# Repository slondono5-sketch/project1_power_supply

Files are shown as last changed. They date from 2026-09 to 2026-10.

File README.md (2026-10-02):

<div align="center">

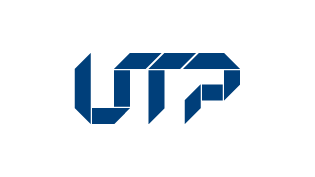
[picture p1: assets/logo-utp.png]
Universidad Tecnológica de Pereira


# ⚡ Fuente de Alimentación Multisalida

**Prototipado Electrónico** · Ingeniería Mecatrónica · 2026-2

*Santiago Londoño Valencia*





</div>

---

## 📌 Descripción

Fuente de laboratorio que convierte la tensión AC de un transformador en cinco salidas DC reguladas, mediante rectificación con puente de diodos, filtrado capacitivo y convertidores DC/DC integrados en la PCB.

## 🔌 Salidas

| Salida | Corriente máx. |
|:---:|:---:|
| **+12 V** | 5 A |
| **+5 V** | 5 A |
| **+3.3 V** | 3 A |
| **−12 V** | 1 A |
| **1.25 – 15 V** | 3 A |

## 📁 Estructura

```
📦 Proyecto
 ┣ 📂 PCB
 ┃ ┗ 📂 Trunk            → Proyecto de Altium Designer
 ┣ 📂 Documentacion      → Especificaciones, requerimientos, diagramas y datasheets
 ┃ ┗ 📂 Diagramas        → Diagrama de diseño de alto nivel en DRAW.IO
 ┣ 📂 Librerias          → Símbolos y footprints propios
 ┗ 📂 assets             → Imágenes del README
```

👉 Empieza por la [documentación del proyecto](Documentacion/README.md).

---

<div align="center">
<sub>Universidad Tecnológica de Pereira · 2026</sub>
</div>

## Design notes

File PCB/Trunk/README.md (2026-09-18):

# project1_power_supply
This project contains the main files for the altium project for the LAB power supply

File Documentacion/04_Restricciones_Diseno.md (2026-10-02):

# 04 – Restricciones de Diseño

## Restricciones eléctricas

| ID | Restricción | Impacto en el diseño |
|---|---|---|
| RD-01 | La entrada es un transformador AC del laboratorio. | Su tensión y potencia limitan el bus DC y la potencia simultánea disponible. Si es menor a 300 VA, no todas las salidas podrán operar a plena carga al mismo tiempo. |
| RD-02 | La rectificación debe hacerse con puente de diodos y filtrado capacitivo. | Se descarta la corrección de factor de potencia y la rectificación síncrona. |
| RD-03 | La tensión del bus DC debe quedar entre ≈ 21 V y ≈ 30 V. | El mínimo garantiza la salida de 15 V; el máximo debe quedar por debajo de la tensión máxima de entrada de los reguladores (40 V). |
| RD-04 | Red eléctrica de 120 VAC, 60 Hz. | El rizado del bus es de 120 Hz, lo que define el tamaño del banco capacitivo. |
| RD-05 | La salida de −12 V debe generarse desde el mismo bus positivo. | Exige una topología inversora; el regulador soporta Vin + |Vout| ≈ 42 V entre sus terminales. |
| RD-06 | Toda la conversión DC/DC debe integrarse en la PCB. | No se permiten módulos DC/DC comerciales externos. |

## Restricciones térmicas

| ID | Restricción | Impacto en el diseño |
|---|---|---|
| RD-07 | Temperatura ambiente de operación de 0 a 40 °C (laboratorio). | Cálculo de disipadores con este ambiente máximo. |
| RD-08 | El puente rectificador y los reguladores disipan varios vatios. | Se requieren disipadores y encapsulados de montaje en disipador (TO-220 / TO-263, puente tipo GBJ o KBPC). |

## Restricciones de fabricación (DFM)

| ID | Restricción | Impacto en el diseño |
|---|---|---|
| RD-09 | Herramienta de diseño: Altium Designer. | Esquemáticos, PCB y librerías propias en Altium. |
| RD-10 | PCB de 2 capas, cobre de 2 oz (70 µm). | Pistas de potencia anchas o polígonos de cobre; el ancho se calcula según IPC-2221 para ≥ 10 A en el bus. |
| RD-11 | Se priorizan componentes THT y SMD de tamaño manejable (≥ 0805). | Facilita el ensamble y la reparación manual. |
| RD-12 | Separación entre la zona de 120 VAC y la de baja tensión. | Distancias de aislamiento (creepage/clearance) en la PCB o primario fuera de la PCB. |

## Restricciones mecánicas

| ID | Restricción | Impacto en el diseño |
|---|---|---|
| RD-13 | Las salidas deben conectarse con bornes de laboratorio. | Bornes tipo binding post / banana de 4 mm rateados para ≥ 10 A. |
| RD-14 | El transformador, los disipadores y el banco de capacitores son voluminosos. | Definen el tamaño mínimo de la PCB y del encapsulado. |
| RD-15 | Se requiere ventilación. | Encapsulado con perforaciones o ventilador. |

## Restricciones del proyecto

| ID | Restricción | Impacto en el diseño |
|---|---|---|
| RD-16 | Presupuesto académico limitado. | Se priorizan reguladores integrados de bajo costo frente a controladores con MOSFET externos. |
| RD-17 | Tiempo de desarrollo de un semestre (2026-2). | Se usan topologías con diseños de referencia del fabricante. |
| RD-18 | Disponibilidad de componentes en Colombia. | Se selecciona una alternativa para cada componente crítico. |

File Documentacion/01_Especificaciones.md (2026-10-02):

# 01 – Especificaciones del Proyecto

## 1. Descripción general

Fuente de alimentación multisalida, alimentada desde un transformador AC del laboratorio, destinada a energizar prototipos y proyectos electrónicos de laboratorio. La energía AC se rectifica con un puente de diodos, se filtra capacitivamente para formar un bus DC no regulado (VIN DC) y desde este bus cinco convertidores DC/DC independientes, integrados en la misma PCB, generan las salidas reguladas.

## 2. Especificaciones de entrada

| Parámetro | Valor |
|---|---|
| Red eléctrica | 120 VAC ±10 %, 60 Hz (Colombia) |
| Transformador | Primario 120 VAC / secundario 18 VAC, potencia ≥ 300 VA |
| Rectificación | Puente de diodos de onda completa |
| Frecuencia de rizado | 120 Hz |
| Filtrado | Banco capacitivo ≈ 30 000 µF |
| Bus DC (VIN DC) nominal | ≈ 24 V |
| Bus DC mínimo (valle de rizado, carga plena, red −10 %) | ≈ 21 V |
| Bus DC máximo (sin carga, red +10 %) | ≈ 30 V |

## 3. Especificaciones de salida

| Salida | Tensión | Corriente máx. | Corriente de diseño (+25 %) | Potencia máx. | Topología |
|---|---|---|---|---|---|
| OUT1 | +12 V | 5 A | 6.25 A | 60 W | Buck |
| OUT2 | +5 V | 5 A | 6.25 A | 25 W | Buck |
| OUT3 | +3.3 V | 3 A | 3.75 A | 9.9 W | Buck |
| OUT4 | −12 V | 1 A | 1.25 A | 12 W | Buck-boost inversor |
| OUT5 | 1.25 – 15 V ajustable | 3 A | 3.75 A | 45 W | Buck ajustable |
| **Total** | | | | **≈ 152 W** | |

Parámetros de calidad objetivo en todas las salidas:

| Parámetro | Objetivo |
|---|---|
| Tolerancia de tensión (salidas fijas) | ±3 % |
| Rizado de salida | ≤ 100 mVpp (≤ 50 mVpp en +3.3 V) |
| Regulación de carga (10 % → 100 %) | ≤ 2 % |
| Eficiencia por convertidor | ≥ 80 % a carga plena |

## 4. Presupuesto de potencia (power budget)

| Salida | P salida | η estimada | P entrada |
|---|---|---|---|
| +12 V | 60 W | 90 % | 66.7 W |
| +5 V | 25 W | 88 % | 28.4 W |
| +3.3 V | 9.9 W | 85 % | 11.6 W |
| −12 V | 12 W | 80 % | 15.0 W |
| Variable | 45 W | 85 % | 52.9 W |
| **Total sobre el bus DC** | **152 W** | | **≈ 175 W** |

- Corriente promedio del bus DC a tensión mínima: 175 W / 21 V ≈ **8.3 A**
- Potencia aparente del transformador (factor ≈ 1.7 por filtro capacitivo): 175 W × 1.7 ≈ **300 VA**
- Corriente de primario: 300 VA / 120 V ≈ **2.5 A**

## 5. Cálculos de la etapa de entrada

**Tensión del bus:**

- Pico del secundario: 18 V × √2 ≈ 25.5 V
- Caída del puente (2 diodos a ~8 A): ≈ 2 V → pico DC ≈ 23.5 V
- Sin carga, la regulación del transformador (~8 %) y la red al +10 % llevan el bus a ≈ 30 V

**Capacitor de filtro:**

C = I / (f · ΔV) = 8.3 A / (120 Hz × 3 V) ≈ 23 000 µF → se especifican 3 × 10 000 µF (30 000 µF), con lo que ΔV ≈ 2.3 Vpp.

**Margen para la salida variable:** con 21 V de bus mínimo y 15 V de salida, el ciclo de trabajo máximo es ≈ 0.71, dentro del rango del convertidor.

## 6. Protecciones especificadas

| Protección | Ubicación |
|---|---|
| Fusible de acción lenta | Primario del transformador |
| Varistor (MOV) | Entrada AC |
| Interruptor de encendido | Primario |
| TVS | Bus DC |
| Fusible / PTC por salida | Cada salida |
| Limitación de corriente y apagado térmico | Integrados en cada regulador |
| Diodo de protección contra tensión inversa | Cada salida |
| Resistencia de descarga | Banco de capacitores |
| LED indicador | Bus DC y cada salida |

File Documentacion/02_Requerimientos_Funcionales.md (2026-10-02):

# 02 – Requerimientos Funcionales

Los requerimientos funcionales describen **qué debe hacer** la fuente de alimentación.

| ID | Requerimiento | Criterio de verificación |
|---|---|---|
| RF-01 | La fuente debe recibir energía desde el transformador AC del laboratorio. | Operación correcta con el transformador especificado. |
| RF-02 | La fuente debe rectificar la tensión AC mediante un puente de diodos de onda completa. | Forma de onda rectificada observada en osciloscopio. |
| RF-03 | La fuente debe filtrar la tensión rectificada mediante un banco capacitivo y generar un bus DC (VIN DC). | Rizado del bus ≤ 3 Vpp a carga plena. |
| RF-04 | La fuente debe entregar +12 V con una corriente de hasta 5 A. | Medición con carga electrónica a 5 A, tolerancia ±3 %. |
| RF-05 | La fuente debe entregar +5 V con una corriente de hasta 5 A. | Medición con carga electrónica a 5 A, tolerancia ±3 %. |
| RF-06 | La fuente debe entregar +3.3 V con una corriente de hasta 3 A. | Medición con carga electrónica a 3 A, tolerancia ±3 %. |
| RF-07 | La fuente debe entregar −12 V con una corriente de hasta 1 A. | Medición con carga electrónica a 1 A, tolerancia ±3 %. |
| RF-08 | La fuente debe entregar una salida ajustable entre 1.25 V y 15 V con una corriente de hasta 3 A. | Barrido del potenciómetro de mínimo a máximo con carga de 3 A. |
| RF-09 | El usuario debe poder ajustar la salida variable mediante un potenciómetro accesible. | Ajuste manual sin herramientas. |
| RF-10 | La conversión DC/DC de todas las salidas debe estar integrada en la PCB de la fuente. | Inspección de la PCB. |
| RF-11 | La fuente debe poder encenderse y apagarse mediante un interruptor general. | Prueba de encendido y apagado. |
| RF-12 | La fuente debe proteger la entrada contra sobrecorriente mediante un fusible. | Inspección y coordinación del fusible. |
| RF-13 | Cada salida debe limitar su corriente ante sobrecarga o cortocircuito sin dañarse. | Prueba de cortocircuito de cada salida. |
| RF-14 | Los reguladores deben apagarse ante sobretemperatura y recuperarse al enfriarse. | Verificación con datasheet y prueba térmica. |
| RF-15 | La fuente debe indicar visualmente la presencia de tensión en el bus DC y en cada salida. | LEDs encendidos en operación normal. |
| RF-16 | Las salidas deben poder usarse simultáneamente y de forma independiente. | Prueba con varias cargas conectadas a la vez. |
| RF-17 | Todas las salidas deben compartir una referencia común (GND). | Verificación de continuidad. |
| RF-18 | El banco de capacitores debe descargarse de forma segura al apagar la fuente. | Tensión del bus < 5 V antes de 60 s después del apagado. |

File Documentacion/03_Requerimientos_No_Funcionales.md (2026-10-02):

# 03 – Requerimientos No Funcionales

Los requerimientos no funcionales describen **cómo** debe comportarse el sistema: calidad, seguridad, confiabilidad y facilidad de uso.

## Desempeño

| ID | Requerimiento |
|---|---|
| RNF-01 | El rizado de cada salida debe ser ≤ 100 mVpp (≤ 50 mVpp en +3.3 V). |
| RNF-02 | La regulación de carga debe ser ≤ 2 % entre 10 % y 100 % de carga. |
| RNF-03 | La eficiencia de cada convertidor DC/DC debe ser ≥ 80 % a carga plena. |
| RNF-04 | La respuesta transitoria ante escalones de carga no debe superar ±5 % de la tensión nominal. |

## Confiabilidad y seguridad

| ID | Requerimiento |
|---|---|
| RNF-05 | Los componentes de potencia deben dimensionarse con un margen de seguridad de 20–30 % sobre la corriente máxima. |
| RNF-06 | Los capacitores deben tener una tensión nominal de al menos 1.5 veces la tensión máxima del bus. |
| RNF-07 | La temperatura de unión de los semiconductores debe permanecer al menos 20 °C por debajo de su máximo a carga plena. |
| RNF-08 | La fuente debe operar en régimen continuo a carga plena durante al menos 1 hora sin degradación. |
| RNF-09 | La sección de 120 VAC debe quedar aislada y protegida contra contacto accidental. |
| RNF-10 | La fuente debe incluir conexión a tierra de protección para el chasis o encapsulado metálico. |

## Usabilidad

| ID | Requerimiento |
|---|---|
| RNF-11 | Las salidas deben estar claramente identificadas por tensión y polaridad. |
| RNF-12 | Los conectores de salida deben permitir conectar cables de laboratorio (bornes banana de 4 mm). |
| RNF-13 | El ajuste de la salida variable debe ser fino (potenciómetro multivuelta). |

## Mantenibilidad y fabricación

| ID | Requerimiento |
|---|---|
| RNF-14 | Los fusibles deben poder reemplazarse sin desoldar componentes. |
| RNF-15 | La PCB debe incluir puntos de prueba en el bus DC y en cada salida. |
| RNF-16 | Cada convertidor debe ocupar una zona propia de la PCB para facilitar diagnóstico y reparación. |
| RNF-17 | Los componentes deben conseguirse en distribuidores nacionales (I+D Electrónica, Sigma Electrónica, Vistronica, Ferretrónica) o internacionales (Digi-Key, Mouser, LCSC). |
| RNF-18 | El proyecto debe documentarse y versionarse en el repositorio Git con la estructura definida. |

## Costo

| ID | Requerimiento |
|---|---|
| RNF-19 | Se deben preferir componentes de bajo costo y amplia disponibilidad sin comprometer los requerimientos eléctricos. |

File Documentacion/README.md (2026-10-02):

# Documentación – Fuente de Alimentación Multisalida para Laboratorio

Proyecto 1 – Prototipado Electrónico (Ingeniería Mecatrónica, UTP 2026-2)

## Contenido de la carpeta

| Archivo | Descripción |
|---|---|
| [01_Especificaciones.md](01_Especificaciones.md) | Especificaciones técnicas del sistema y presupuesto de potencia |
| [02_Requerimientos_Funcionales.md](02_Requerimientos_Funcionales.md) | Qué debe hacer la fuente |
| [03_Requerimientos_No_Funcionales.md](03_Requerimientos_No_Funcionales.md) | Cómo debe hacerlo (calidad, seguridad, mantenibilidad) |
| [04_Restricciones_Diseno.md](04_Restricciones_Diseno.md) | Limitaciones técnicas, económicas y de fabricación |
| [05_Lista_Preliminar_Componentes.md](05_Lista_Preliminar_Componentes.md) | Componentes principales seleccionados y su justificación |
| [Diagramas/](Diagramas/README.md) | Diagrama de Bloques de Alto Nivel (HBLD) en PNG y archivo editable .drawio |

## Flujo de diseño

Requisitos del sistema → Especificaciones → Arquitectura por bloques → Selección de componentes → Captura de esquemáticos

## Control de versiones

| Versión | Fecha | Descripción |
|---|---|---|
| 0.1 | 2026-10 | Documentación inicial |
| 0.2 | 2026-10 | Se agrega el Diagrama de Bloques de Alto Nivel (HBLD) |

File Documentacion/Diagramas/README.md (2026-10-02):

<div align="center">

# 🧩 Diagrama de Bloques de Alto Nivel (HBLD)

**Fuente de Alimentación Multisalida** · Prototipado Electrónico · UTP 2026-2

</div>

---

<div align="center">

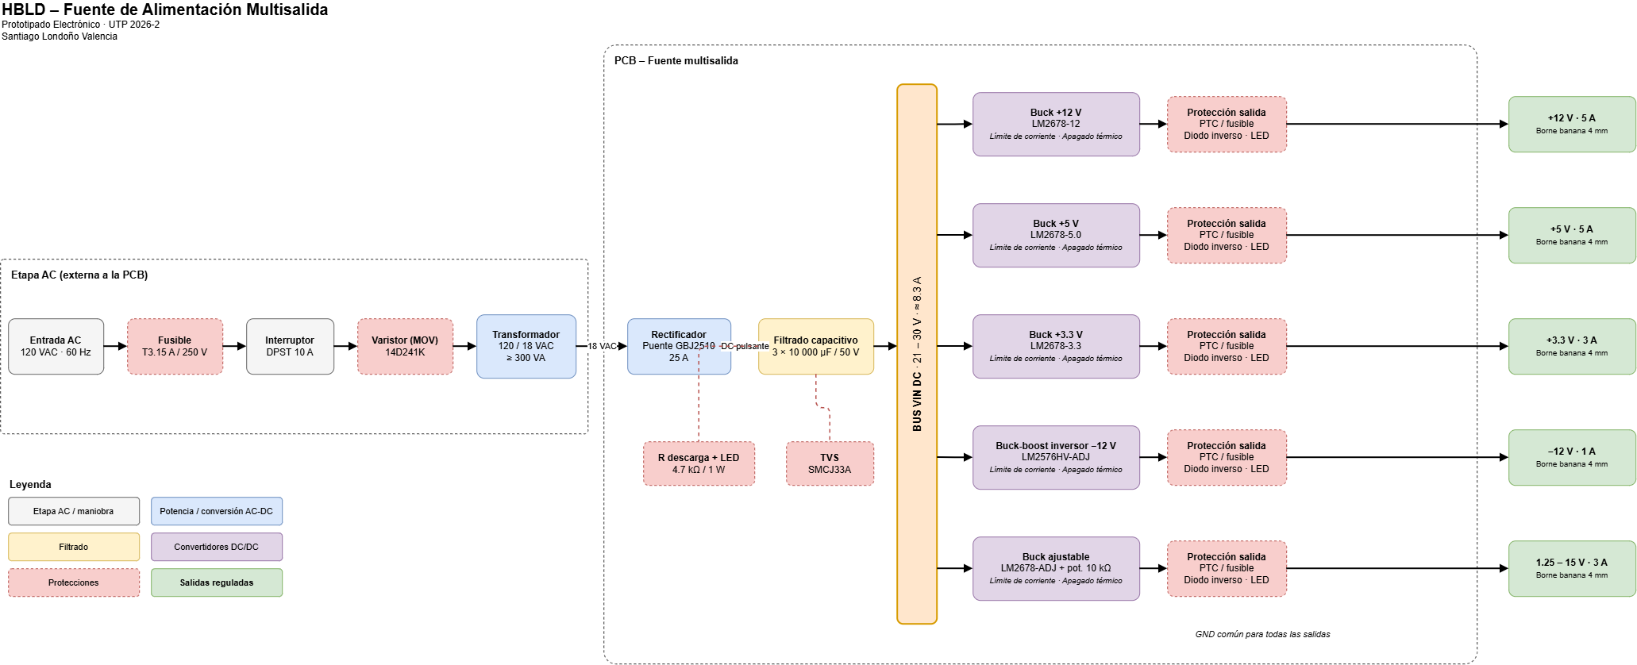
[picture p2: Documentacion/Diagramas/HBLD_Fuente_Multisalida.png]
Diagrama de bloques de alto nivel de la fuente multisalida


<br/><br/>




</div>

---

### 📖 Cómo leer el diagrama

| Color | Bloque |
|:---:|---|
| ⬜ | Etapa AC y maniobra |
| 🟦 | Potencia / conversión AC-DC |
| 🟨 | Filtrado |
| 🟪 | Convertidores DC/DC |
| 🟥 | Protecciones |
| 🟩 | Salidas reguladas |

<sub>⬅️ [Volver a la documentación](../README.md)</sub>

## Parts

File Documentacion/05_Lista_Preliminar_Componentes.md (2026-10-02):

# 05 – Lista Preliminar de Componentes Principales

> Lista preliminar sujeta a validación en el diseño detallado. Los datasheets se almacenan en `Documentacion/Datasheets/`.

## Resumen

| # | Bloque | Componente propuesto | Especificación clave | Alternativa |
|---|---|---|---|---|
| 1 | Transformador de entrada | Transformador 120 VAC / 18 VAC | ≥ 300 VA, 60 Hz (toroidal preferido) | Transformador de laboratorio equivalente |
| 2 | Puente rectificador | GBJ2510 | 25 A, 1000 V | KBPC3510 (35 A) |
| 3 | Capacitores de filtrado | 3 × electrolítico snap-in 10 000 µF / 50 V | 105 °C, baja ESR | 4 × 6 800 µF / 50 V |
| 4 | Buck +12 V | LM2678-12 | 5 A, Vin 8–40 V, 260 kHz | LM5116 (controlador, MOSFET externos) |
| 5 | Buck +5 V | LM2678-5.0 | 5 A, Vin 8–40 V | LM5116 |
| 6 | Buck +3.3 V | LM2678-3.3 | 5 A, Vin 8–40 V | LM2596-3.3 (3 A, sin margen) |
| 7 | Convertidor −12 V | LM2576HV-ADJ (buck-boost inversor) | 3 A de switch, Vin hasta 60 V | LM2576-ADJ (40 V) |
| 8 | Regulador variable | LM2678-ADJ + potenciómetro multivuelta | 5 A, Vref ≈ 1.21 V | LM2596-ADJ (3 A, sin margen) |
| 9 | Fusible de entrada | Fusible 5×20 mm T3.15 A / 250 V + portafusible | Acción lenta | T4 A según transformador |
| 10 | Interruptor | Interruptor basculante DPST 250 VAC / 10 A con luz | Corta fase y neutro | SPST 10 A |
| 11 | Conectores | Entrada: bornera 2 pines 5.08 mm. Salidas: bornes banana 4 mm | ≥ 15 A | Bornera de tornillo 7.62 mm |

## Justificación por bloque

### 1. Transformador de entrada
Un secundario de 18 VAC genera un bus de ≈ 24 V, suficiente para la salida de 15 V con margen de caída, y por debajo de los 40 V máximos de los reguladores incluso sin carga y con la red al +10 %. La potencia de ≥ 300 VA cubre los ≈ 175 W del bus con el factor de forma del filtro capacitivo (≈ 1.7).

### 2. Puente rectificador – GBJ2510
La corriente promedio del bus es ≈ 8.3 A y los picos de carga del capacitor son varias veces mayores. Un puente de 25 A ofrece un margen holgado y su encapsulado plano se monta fácilmente en disipador.

### 3. Capacitores de filtrado – 3 × 10 000 µF / 50 V
C = 8.3 A / (120 Hz × 3 V) ≈ 23 000 µF; con 30 000 µF el rizado baja a ≈ 2.3 Vpp. Los 50 V dan un margen de ≈ 1.6 veces sobre los 30 V máximos del bus. Repartir en tres capacitores distribuye la corriente de rizado (≈ 13 A RMS en total). Se debe verificar el rating de rizado de la referencia final.

### 4, 5 y 6. Buck +12 V, +5 V y +3.3 V – familia LM2678
- Tensión de entrada de hasta 40 V, compatible con el bus.
- Versiones fijas de 3.3, 5 y 12 V, lo que reduce componentes externos.
- Limitación de corriente y apagado térmico integrados (RF-13, RF-14).
- Usar la misma familia en cuatro salidas simplifica la librería de Altium y la compra.

**Riesgo identificado:** en +12 V y +5 V la corriente requerida (5 A) coincide con la nominal del LM2678, por lo que no cumple el margen de 25 % de RNF-05. Para el prototipo se acepta con un diseño térmico cuidadoso. Si se exige el margen completo, la alternativa es el controlador LM5116 con MOSFET externos. En +3.3 V el LM2678 sí cumple el margen (5 A frente a 3.75 A requeridos).

### 7. Convertidor −12 V – LM2576HV-ADJ en buck-boost inversor
Genera tensión negativa desde el bus positivo sin necesidad de un devanado adicional. En configuración inversora el regulador soporta Vin + |Vout| ≈ 30 + 12 = 42 V, por encima de los 40 V del LM2576 estándar, y por eso se elige la versión HV (60 V). La corriente pico del switch es ≈ 1.25 A × (21 + 12) / 21 ≈ 2 A más el rizado, dentro de los 3 A del dispositivo.

### 8. Regulador variable – LM2678-ADJ
Su tensión de referencia de ≈ 1.21 V cubre el mínimo de 1.25 V especificado. Ser conmutado evita la disipación de un regulador lineal: un LM317 a 1.25 V y 3 A disiparía (21 − 1.25) × 3 ≈ 60 W. La capacidad de 5 A cumple el margen sobre los 3 A requeridos. El ajuste se hace con un potenciómetro multivuelta de 10 kΩ en la red de realimentación: con R1 = 820 Ω, Vout = 1.21 × (1 + R2 / R1) va de ≈ 1.21 V a ≈ 15.9 V; se puede añadir una resistencia en serie para limitar el máximo a 15 V.

### 9. Fusible de entrada – T3.15 A
La corriente nominal del primario es ≈ 2.5 A. Se requiere acción lenta por la corriente de arranque del transformador y del banco de 30 000 µF.

### 10. Interruptor – DPST 10 A
Interrumpe fase y neutro por seguridad. El indicador luminoso cumple parte de RF-15.

### 11. Conectores
Los bornes banana de 4 mm son el estándar de laboratorio (RNF-12) y soportan las corrientes de salida. La entrada desde el transformador usa una bornera de potencia.

## Componentes complementarios

| Componente | Referencia preliminar | Función |
|---|---|---|
| Varistor de entrada | 14D241K (150 VAC) | Supresión de transitorios de red |
| TVS del bus DC | SMCJ33A | Supresión de transitorios en el bus (verificar tensión de clamp frente al máximo de los reguladores) |
| Diodos Schottky de los buck | MBR1045 (10 A, 45 V) | Diodo de rueda libre |
| Inductores de potencia | Según tablas del datasheet o TI WEBENCH (≥ 7 A de saturación en 12 V y 5 V) | Almacenamiento de energía |
| Fusibles de salida | PTC reseteable o fusible de cuchilla por salida | Protección por salida |
| Resistencia de descarga | 4.7 kΩ / 1 W | Descarga del banco de capacitores |
| LEDs indicadores | LED 3 mm + resistencia limitadora | Indicación de bus y salidas |
| Disipadores | Aluminio para TO-220 y puente | Gestión térmica |

## Distribuidores sugeridos

Nacionales: I+D Electrónica, Sigma Electrónica, Vistronica, Ferretrónica.
Internacionales: Digi-Key, Mouser, LCSC, Octopart (comparador).

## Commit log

2026-10-02 añadir archivos altium
    [PCB1.PcbDoc, Sheet1.SchDoc, project1_power_supply.PrjPcb]
2026-10-02 Add design flow section to README
    Updated the README to include a new section on design flow.
